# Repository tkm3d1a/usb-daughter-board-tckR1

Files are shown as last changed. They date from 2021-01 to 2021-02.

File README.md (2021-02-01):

# usb-daughter-board-tckR1
 USB Type-C Daughter Board - TKDesign - R1

Intent is to be a general purpose USB-C Daughter board, meant to break out the circuit onto a single board, meant for use in future KB design ideas.

All work will be done in KiCad as I learn it, this is meant to be the initial revision only, future revs will get new repos as major design shifts happen.

Initial idea is for SMT with production from a board manufacturer.  Break out will be done through a planned JST style connector. Breakout will be D+/D-/VCC/GND.

More info to be added through devolpment.

//////////UPDATE 1://///////////

Initial Prototype Board ordered for testing 1/31/2021

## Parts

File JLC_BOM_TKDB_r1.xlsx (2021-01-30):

Comment | Designator | Footprint | LCSC Part #（optional）
500@100mhz | FB1,FB2 | 0805_I | C281168
500ma | F1 | 0805_Fuse | C261942 (https://lcsc.com/product-detail/PTC-Resettable-Fuses_TLC-Electronic-TLC-PSMD050_C261942.html/?href=jlc-SMT)
PRTR5V0U2X | D1 | SOT-143 | C12333 (https://lcsc.com/product-detail/Diodes-ESD_Nexperia_PRTR5V0U2X-215_PRTR5V0U2X-215_C12333.html/?href=jlc-SMT)
5.1kΩ | R1,R2 | 0805_R
JST 4pin | J1 | 1x04-1MP_P1.00mm_Horizontal | C160404

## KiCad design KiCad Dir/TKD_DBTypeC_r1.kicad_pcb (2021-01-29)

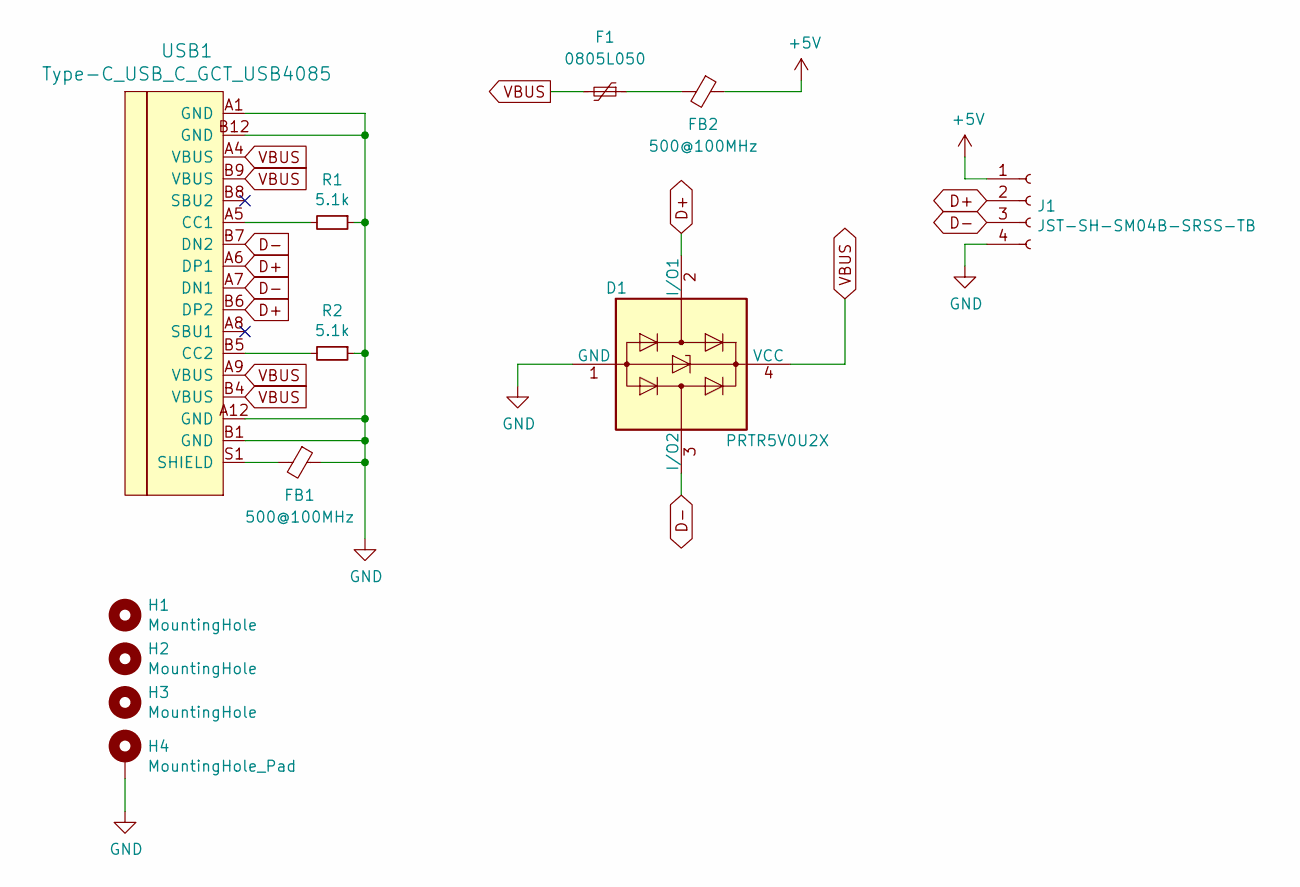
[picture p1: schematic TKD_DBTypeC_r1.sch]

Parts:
D1: PRTR5V0U2X; SOT-143
F1: 0805L050; Fuse_0805_2012Metric
FB1, FB2: 500@100MHz; L_0805_2012Metric
H1, H2, H3: MountingHole; MountingHole_2.7mm_M2.5_DIN965_Pad
H4: MountingHole_Pad; MountingHole_2.7mm_M2.5_DIN965_Pad
J1: JST-SH-SM04B-SRSS-TB; JST_SH_SM04B-SRSS-TB_1x04-1MP_P1.00mm_Horizontal
R1, R2: 5.1k; R_0805_2012Metric
USB1: Type-C_USB_C_GCT_USB4085; USB_C_Receptacle_GCT_USB4085

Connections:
+5V: FB2.1, J1.1
D+: D1.2 (I/O1), J1.2, USB1.A6 (DP1), USB1.B6 (DP2)
D-: D1.3 (I/O2), J1.3, USB1.A7 (DN1), USB1.B7 (DN2)
GND: D1.1 (GND), FB1.1, H4.1, J1.4, R1.1, R2.1, USB1.A1 (GND), USB1.A12 (GND), USB1.B1 (GND), USB1.B12 (GND)
unnamed: F1.1, FB2.2
unnamed: FB1.2, USB1.S1 (SHIELD)
unnamed: R1.2, USB1.A5 (CC1)
unnamed: R2.2, USB1.B5 (CC2)
VBUS: D1.4 (VCC), F1.2, USB1.A4 (VBUS), USB1.A9 (VBUS), USB1.B4 (VBUS), USB1.B9 (VBUS)

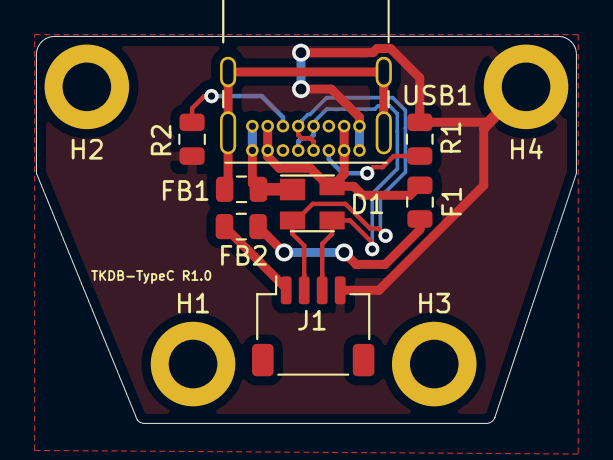
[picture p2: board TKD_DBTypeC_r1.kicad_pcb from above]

Board: 2 copper layers, 30.0 x 21.5 mm, 12 parts (0 on the bottom side), 9 nets.

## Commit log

2021-01-12 some boardlayout work
    [TKD_DBTypeC_r1.kicad_pcb, TKD_DBTypeC_r1.sch]
2021-01-18 pcb/schemea update
    [TKD_DBTypeC_r1.kicad_pcb, TKD_DBTypeC_r1.sch]
2021-01-29 Edge cuts placed, r1 done
    [TKD_DBTypeC_r1.kicad_pcb]
2021-01-29 gerber files - r1
    [TKD_DBTypeC_r1-B_Cu.gbr, TKD_DBTypeC_r1-B_Mask.gbr, TKD_DBTypeC_r1-B_Paste.gbr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]
2021-01-30 BOM generation - completed order #1
    [JLC_BOM_TKDB_r1.xlsx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]
